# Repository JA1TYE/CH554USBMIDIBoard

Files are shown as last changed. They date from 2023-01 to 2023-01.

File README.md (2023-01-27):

# CH554 USB-MIDI Host Board

This board is designed to use [WCH's 8-bit MCU CH554](http://wch-ic.com/products/CH554.html) as a USB-MIDI Host.

Firmware for this board is available on [CH554USBMIDIHost](https://github.com/JA1TYE/CH554USBMIDIHost).

## How to use
CH554's UART0(TX:P3.1/RX:P3.0) are used as MIDI 1.0 I/F. 
CH554's UART1(TX:P1.7/RX:P1.6) are used for debugging.

This board have MIDI 1.0 compatible TX circuit(some resistors to consist current loop) but circuit for RX(i.e. optoisolator) is not contained. If you use MIDI1.0 RX, you should add optoisolator and so on.

You can use USB-A port and DEBUG UART (UART1) port to write firmware to CH554.
You need to power on with pressing SW1 to enter bootloader mode.

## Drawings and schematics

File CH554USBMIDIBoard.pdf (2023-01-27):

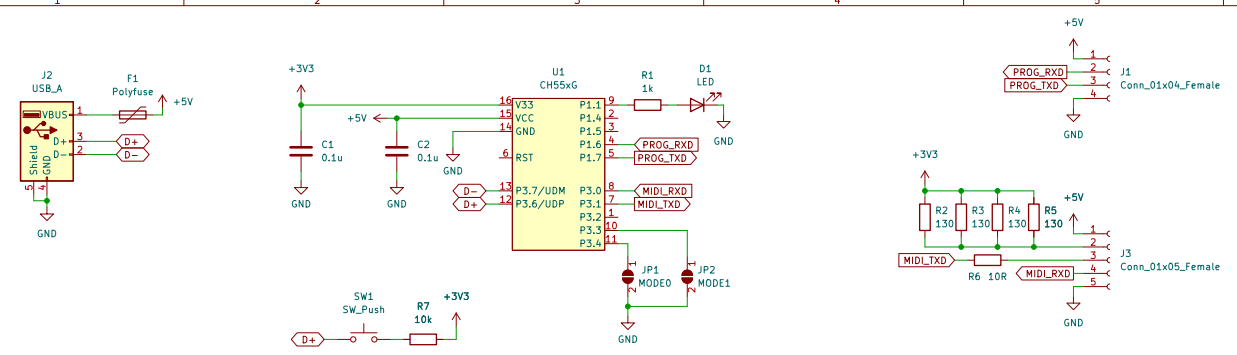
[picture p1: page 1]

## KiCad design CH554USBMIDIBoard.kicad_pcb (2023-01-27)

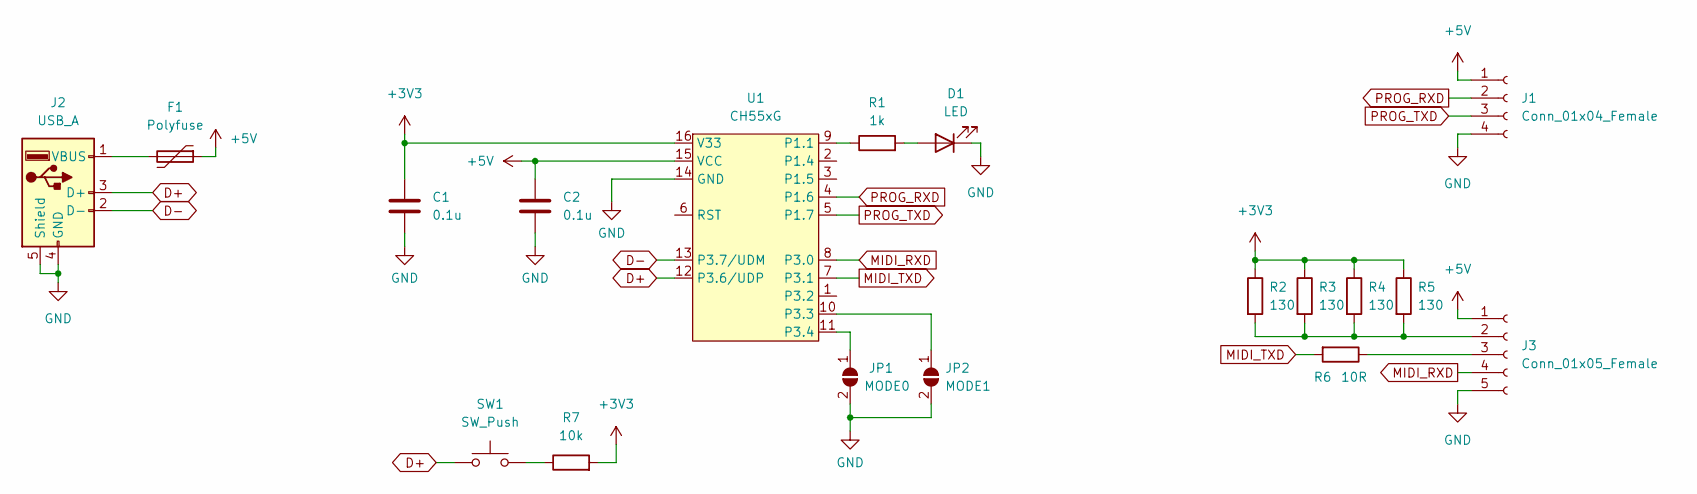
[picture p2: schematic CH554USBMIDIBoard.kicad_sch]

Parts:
C1, C2: 0.1u; C_0402_1005Metric
D1: LED; LED_0603_1608Metric
F1: Polyfuse; Fuse_1812_4532Metric
J1: Conn_01x04_Female; PinHeader_1x04_P2.54mm_Vertical
J2: USB_A; USB_A_Molex_67643_Horizontal
J3: Conn_01x05_Female; PinHeader_1x05_P2.54mm_Vertical
JP1: MODE0; SolderJumper-2_P1.3mm_Open_TrianglePad1.0x1.5mm
JP2: MODE1; SolderJumper-2_P1.3mm_Open_TrianglePad1.0x1.5mm
R1: 1k; R_0402_1005Metric
R2, R3, R4, R5: 130; R_0805_2012Metric
R6: 10R; R_0603_1608Metric
R7: 10k; R_0402_1005Metric
SW1: SW_Push; SW_Push_SPST_NO_Alps_SKRK
U1: CH55xG; SO-16_3.9x9.9mm_P1.27mm

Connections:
+3V3: C1.1, R2.1, R3.1, R4.1, R5.1, R7.2, U1.16 (V33)
+5V: C2.1, F1.1, J1.1, J3.1, U1.15 (VCC)
D+: J2.3 (D+), SW1.1, U1.12 (P3.6/UDP)
D-: J2.2 (D-), U1.13 (P3.7/UDM)
GND: C1.2, C2.2, D1.1 (K), J1.4, J2.4 (GND), J2.5 (Shield), J3.5, JP1.2 (B), JP2.2 (B), U1.14 (GND)
MIDI_RXD: J3.4, U1.8 (P3.0)
MIDI_TXD: R6.2, U1.7 (P3.1)
unnamed: D1.2 (A), R1.2
unnamed: F1.2, J2.1 (VBUS)
unnamed: J3.2, R2.2, R3.2, R4.2, R5.2
unnamed: J3.3, R6.1
unnamed: JP1.1 (A), U1.11 (P3.4)
unnamed: JP2.1 (A), U1.10 (P3.3)
unnamed: R1.1, U1.9 (P1.1)
unnamed: R7.1, SW1.2
PROG_RXD: J1.2, U1.4 (P1.6)
PROG_TXD: J1.3, U1.5 (P1.7)

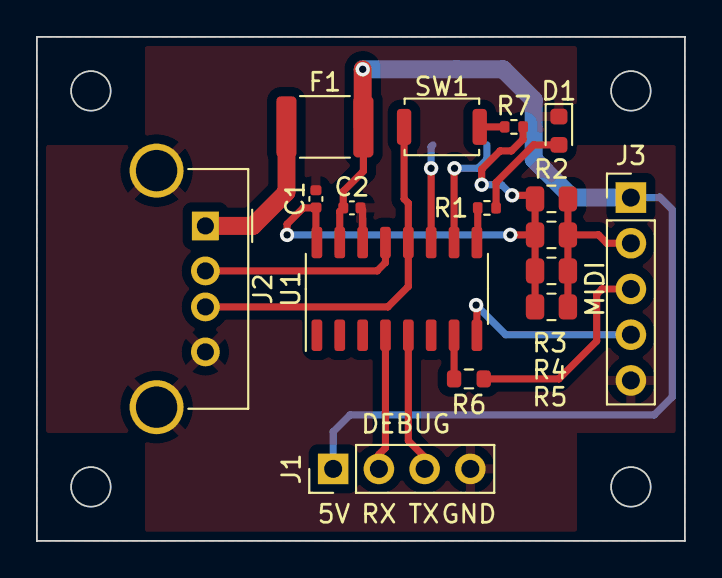
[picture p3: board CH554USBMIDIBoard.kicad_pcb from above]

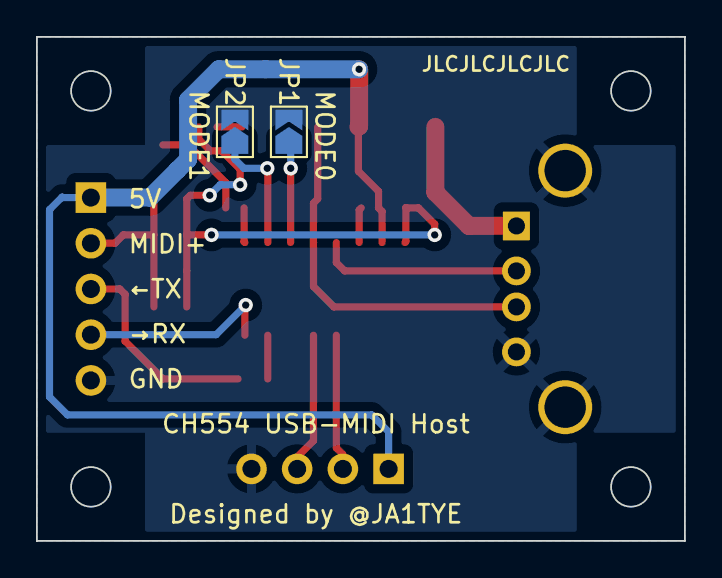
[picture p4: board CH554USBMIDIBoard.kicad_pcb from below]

Board: 2 copper layers, 36.0 x 28.0 mm, 18 parts (2 on the bottom side), 17 nets.
